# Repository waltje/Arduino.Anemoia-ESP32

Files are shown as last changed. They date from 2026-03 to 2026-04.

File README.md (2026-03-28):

<h1 align="center">
  <br>
  Anemoia
  <br>
  <b>Anemoia-ESP32</b>
  <br>
</h1>

<p align="center">
  Anemoia-ESP32 is a rewrite and port of the Anemoia Nintendo Entertainment System (NES) emulator running directly on the ESP32.  
  It is written in C++ and is designed to bring classic NES games to the ESP32.  
  This project focuses on performance, being able to run the emulator at native speeds and with full audio emulation implemented. However, games with complex mappers may induce a small speed loss.
  <br/>
  Anemoia-ESP32 is available on GitHub under the <a href="https://github.com/Shim06/Anemoia-ESP32/blob/main/LICENSE" target="_blank">GNU General Public License v3.0 (GPLv3)</a>.
</p>

<div align="center">
  <video src="https://github.com/user-attachments/assets/2b766040-4717-4ae2-9f72-5637c5ec5cd3"> </video>
</div>

---

## Sponsor

[NextPCB](https://www.nextpcb.com?code=Shim)

This project is proudly sponsored by [NextPCB](https://www.nextpcb.com?code=Shim). Their support helps fund the development and continuation of this project, and I'm very grateful to have them as my first ever sponsor. 

Want to make a PCB? NextPCB offers PCB fabrication and assembly services with fast turnaround times and affordable pricing to help bring your electronics projects to the next level.

---

## Table of Contents

- [Performance](#performance)
- [Compatibility](#compatibility)
- [Hardware Overview](#hardware-overview)
  - [Where to Buy](#where-to-buy)
  - [Default Pin Setup](#default-pin-setup)
- [Controls](#controls)
  - [Menu Access](#menu-access)
  - [Controller Button Mappings](#controller-button-mappings)
- [Getting Started](#getting-started)
  - [Option 1 - Web Flash](#option-1---web-flash-recommended)
  - [Option 2 - Build from Source](#option-2---build-from-source)
  - [After Flashing](#after-flashing)
- [How to Build and Upload](#how-to-build-and-upload)
- [Contributing](#contributing)
- [License](#license)

---

## Performance
Anemoia-ESP32 is heavily optimized to achieve native NES speeds on the ESP32, running at ~60.098 FPS (NTSC) with 1 frame skip and full audio emulation enabled.

Here are the performance benchmarks for several popular NES games. 
> [!NOTE]
> The following benchmarks show average framerates recorded over 8192 frames (~2 minutes) of emulation time. Some games, such as `Kirby's Adventure`, which frequently switch banks may experience significant FPS drops in certain sections.

| Game | Mapper | Average FPS |
|---|---|---|
| **Super Mario Bros.** | NROM (0)  | **60.10 FPS** |
| **Contra** | UxROM (2) | **60.10 FPS** |
| **The Legend of Zelda** | MMC1 (1)  | **60.10 FPS** |
| **Mega Man 2** | MMC1 (1)  | **60.10 FPS** |
| **Castlevania** | UxROM (2) | **60.10 FPS** |
| **Metroid** | MMC1 (1)  | **60.10 FPS** |
| **Kirby’s Adventure** | MMC3 (4)  | **59.57 FPS** |
| **Donkey Kong** | NROM (0)  | **60.10 FPS** |

## Compatibility

As of now, Anemoia-ESP32 has implemented six major memory mappers:
* Mapper 0
* Mapper 1
* Mapper 2
* Mapper 3
* Mapper 4
* Mapper 69

Totalling to around 79% of the entire NES game catalogue. 

If you'd like to check if a certain game is supported, visit 
[NesCartDB](https://nescartdb.com/) and search for the game on the 
right-hand side of the site. Select the specific game version
and look for the `iNES Mapper` number in the cart properties.
The game should be supported if the iNES Mapper number is in the list
of implemented mappers above.

Feel free to open an issue if a game has glitches or fails to boot.

---

## Hardware Overview
Anemoia-ESP32 requires a dual-core ESP32 with a minimum of 1 MB flash memory and <u><strong>NO PSRAM IS REQUIRED</strong></u>.

- ESP32
  - e.g. ESP32-DevKitC or ESP32-WROOM-32
- A 320x240 SPI TFT screen (no touch needed)
  - Either an ST7789-based screen as depicted, or
  - an ILI9341-based screen with 320x240 pixels
- Audio Amplifier
  - e.g. a PAM8403 or PAM8302
- Speaker
- MicroSD card module
- 8 Tactile push buttons, or
- Supported Controller
  - NES controller
  - SNES controller
  - PS1 controller
  - PS2 controller

> [!NOTE]
> ST7789-based displays are recommended as they seem to fare better with 80MHz SPI speeds and are the most compatible. ILI9341-based screens may experience screen problems at higher SPI speeds.

## Where to Buy
These are the recommended parts to use for this project.<br>
*These are affiliate links. Buying through them helps support me at no extra cost to you. Thank you for your support.*

- [ESP32](https://s.click.aliexpress.com/e/_c3B4YJhz)
- [240x320 ST7789 Display](https://s.click.aliexpress.com/e/_c2wkMWbV)
- [PAM8403 Amplifier Module](https://s.click.aliexpress.com/e/_c3EWffgT)
- [MicroSD Card Module](https://s.click.aliexpress.com/e/_c3ORlv7p)
- [TP4056 Charging Module](https://s.click.aliexpress.com/e/_c2xSu8Mn)
- [S09 Buck Converter](https://s.click.aliexpress.com/e/_c4LFB5JD)
- [SS12F17 Slide Switch](https://s.click.aliexpress.com/e/_c3DdrYLV)
- [12×12×7.3mm Tactile Push Buttons](https://s.click.aliexpress.com/e/_c3ABhrhV)
- [40mm Speaker](https://s.click.aliexpress.com/e/_c4Ci9359)

## Default Pin Setup
Default pin schematic

### TFT Display
| Signal | ESP32 Pins |
|---|---|
| MOSI | GPIO23 |
| MISO | -1 (N/A) |
| SCLK | GPIO18 |
| CS | GPIO4 |
| DC | GPIO2 |
| RST | EN |

### MicroSD
| Signal | ESP32 Pins |
|---|---|
| MOSI | GPIO13 |
| MISO | GPIO12 |
| SCLK | GPIO14 |
| CS | GND |

> [!IMPORTANT]
> 3V3-microsd-module-img
>
> If using this **3.3V microSD card module**, the pull-up resistor on **MISO (GPIO12)** must be **removed**. GPIO12 is a bootstrapping pin (MTDI) that must be LOW during boot. The external pull-up on the microSD module conflicts with the boot strapping process, preventing the ESP32 from booting correctly.

### Audio Amplifier
| Signal | ESP32 Pins |
|---|---|
| Input | GPIO25 |
              
### Controller
There are currently three input methods: Tactile push buttons, an NES/SNES controller, and a PS1/PS2 controller.

### Tactile Push Buttons
| Signal | ESP32 Pins |
|---|---|
| A | GPIO19 & GND |
| B | GPIO26 & GND |
| Left | GPIO32 & GND |
| Right | GPIO33 & GND |
| Up | GPIO15 & GND |
| Down | GPIO5 & GND |
| Start | GPIO27 & GND |
| Select | GPIO16 (RX2) & GND |
<br>

### NES/SNES controller

NES/SNES controller Pinout

| Signal | ESP32 Pins |
|---|---|
| Clock | GPIO22 |
| Latch | GPIO27 |
| Data | GPIO35 |
<br>

### PS1/PS2 controller

PS1/PS2 controller Pinout

| Signal | ESP32 Pins |
|---|---|
| Data | GPIO17 (TX2) |
| Command | GPIO22 |
| Attention | GPIO19 |
| Clock | GPIO23 |
<br>

Also connect the power and ground lines if using a controller. 
Most controllers should work fine from 3.3V power supply. 

---

## Controls

### Menu Access
Press **Start + Select** simultaneously in a game to open the menu.

### Controller Button Mappings

#### SNES Controller
| NES Button | SNES Buttons |
|---|---|
| A | B, A, R |
| B | Y, X, L |
| Start | Start |
| Select | Select |
| Up | D-Pad Up |
| Down | D-Pad Down |
| Left | D-Pad Left |
| Right | D-Pad Right  |

#### PS1/PS2 Controller
| NES Button | PS1/PS2 Buttons |
|---|---|
| A | R1, R2, R3, X, O |
| B | L1, L2, L3, Square, Triangle |
| Start | Start |
| Select | Select |
| Up | D-Pad Up |
| Down | D-Pad Down |
| Left | D-Pad Left |
| Right | D-Pad Right |

---

## Getting Started

### Option 1 - Web Flash (Recommended)
No software installation required.

1. Visit the [Web Flash](https://shim06.github.io/Anemoia-ESP32/) website.
2. Connect your ESP32 via USB.
3. Click **Flash** and select your ESP32's COM port.

> [!NOTE]
> Web flashing requires a Chromium-based browser (Chrome, Edge, Opera) with WebSerial support. Firefox is not supported.

### Option 2 - Build from Source

1. Build and upload the `Anemoia-ESP32.ino` program into the ESP32 following the [How to build and upload](#how-to-build-and-upload) instructions below.

---
### After Flashing
1. Format your microSD card to `FAT32`.
2. Put .nes game roms inside the root of the microSD card.
3. Insert the microSD card into the microSD card module.
4. Power on the ESP32 and select a game from the file select menu.

## How to build and upload

### Step 1

Either use `git clone https://github.com/Shim06/Anemoia-ESP32.git` on the command line to clone the repository or use Code → Download zip button and extract to get the files.

### Step 2
1. Download and install the Arduino IDE. 
2. In <b> File → Preferences → Additional boards manager URLs </b> , add:
```cmd
https://espressif.github.io/arduino-esp32/package_esp32_index.json
```
3. Download the ESP32 board support `v3.2.1` through <b> Tools → Board → Boards Manager </b>. 
> [!IMPORTANT]
> Make sure to download version 3.2.1, as different board versions may have worse performance.
4. Download the `SdFat` and `TFT_eSPI` libraries from <b> Tools → Manage Libraries </b>.

### Step 3 - Configure TFT_eSPI
Copy and paste the TFT_eSPI configuration file into the TFT_eSPI folder.
1. Navigate to your Arduino Libraries folder:
(Default location): `Documents/Arduino/libraries/TFT_eSPI`
2. Copy the provided `User_Setup.h` file from this repository into
`TFT_eSPI/` and overwrite the file. Optionally, edit the `#define` pins as desired.
> [!NOTE]
> If using a screen with the ILI9341 driver, open `User_Setup.h` in a text editor and comment out `#define ST7789_DRIVER` and uncomment `#define ILI9341_DRIVER`.
> ```C++
> // #define ST7789_DRIVER
> #define ILI9341_DRIVER
> ```

### Step 4 - Apply custom build flags
1. Locate your ESP32 Arduino platform directory. This is typically at:
```cmd
\Users\{username}\AppData\Local\Arduino15\packages\esp32\hardware\esp32\{version}\
```
2. Copy the `platform.txt` file from this repository and paste into that folder.
This file defines additional compiler flags and optimizations used by Anemoia-ESP32.
> [!WARNING]
> Backup your `platform.txt` file if you have your own custom settings already. 

### Step 5 - Upload
1. Connect your ESP32 via USB.
2. In the Arduino IDE, go to <b> Tools → Board </b> and select your ESP32 board (e.g., ESP32 Dev Module).
3. Click Upload or press `Ctrl+U` to build and flash the emulator. Optionally, edit the `#define` pins as desired.

## Contributing

Pull requests are welcome. For major changes, please open an issue first
to discuss what you would like to change.

## License

This project is licensed under the GNU General Public License v3.0 (GPLv3) - see the [LICENSE](LICENSE) file for more details.

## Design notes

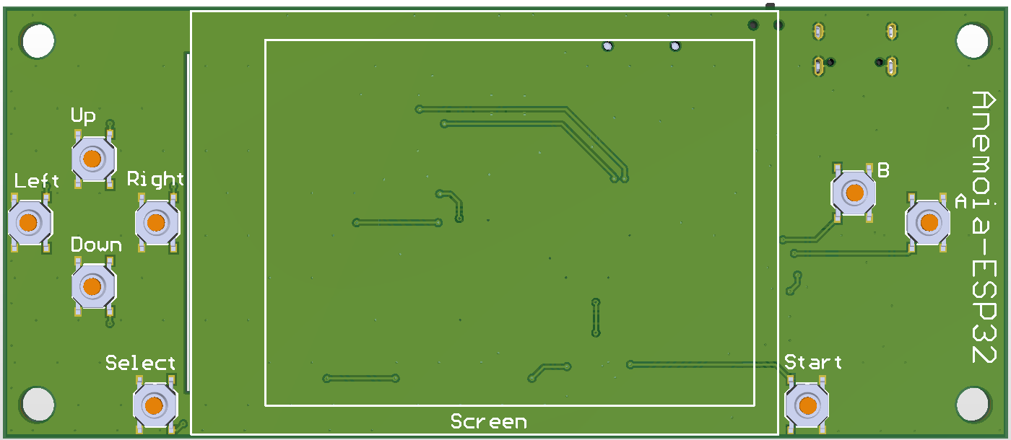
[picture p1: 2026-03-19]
hardware/Anemoia-ESP32-SMD/pcb/Anemoia-ESP32-SMD-Bottom.png

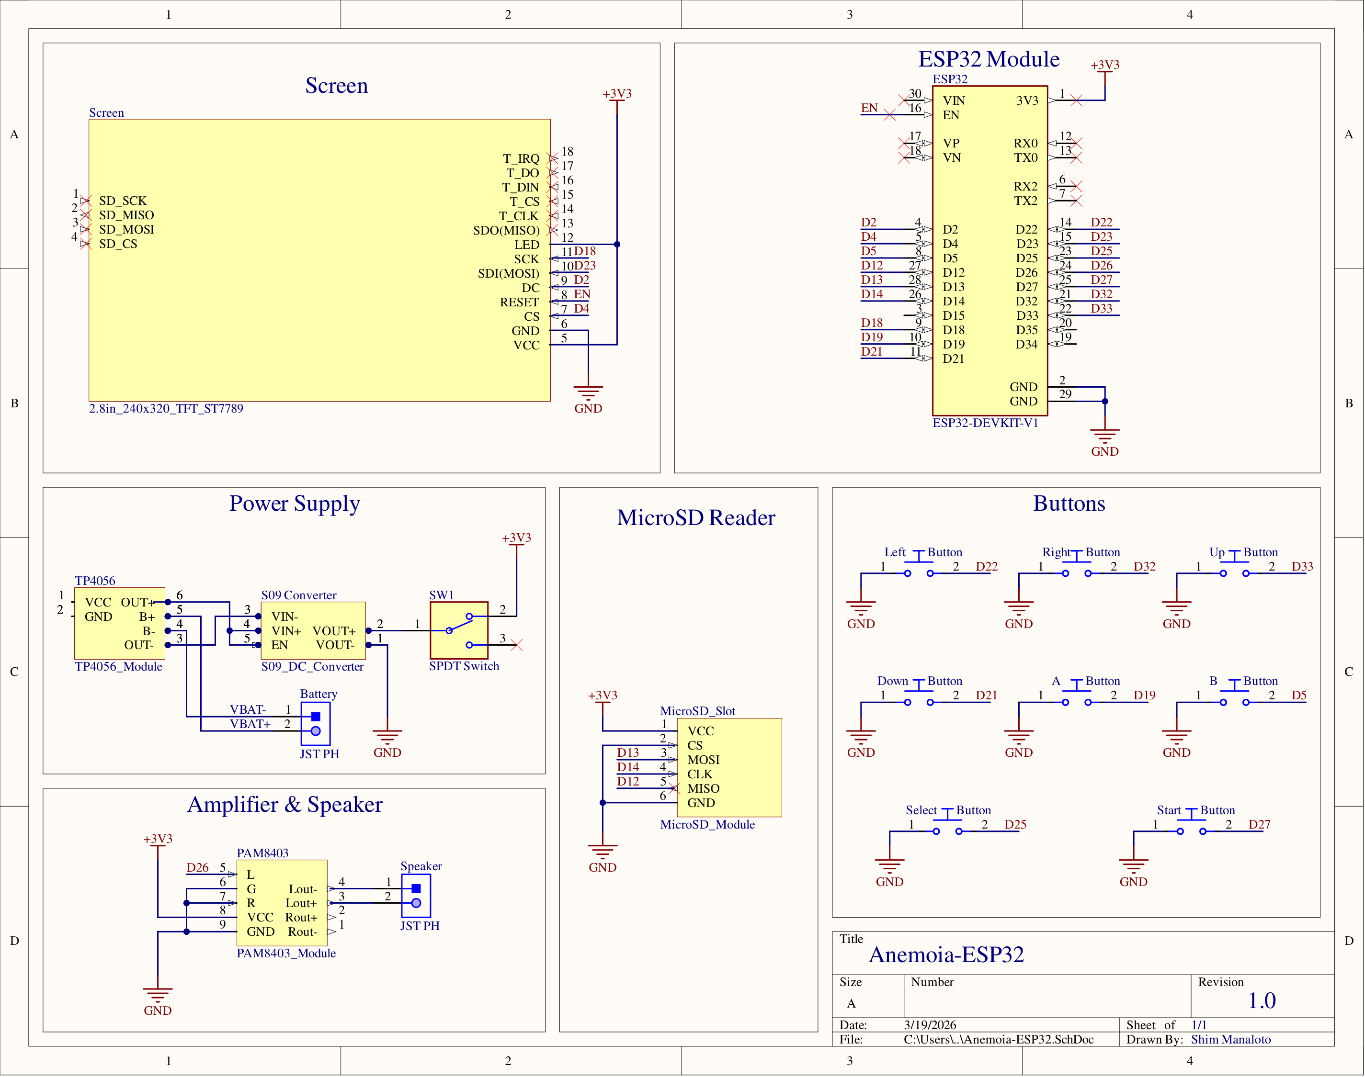
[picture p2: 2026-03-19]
hardware/Anemoia-ESP32/schematics/Anemoia-ESP32.png

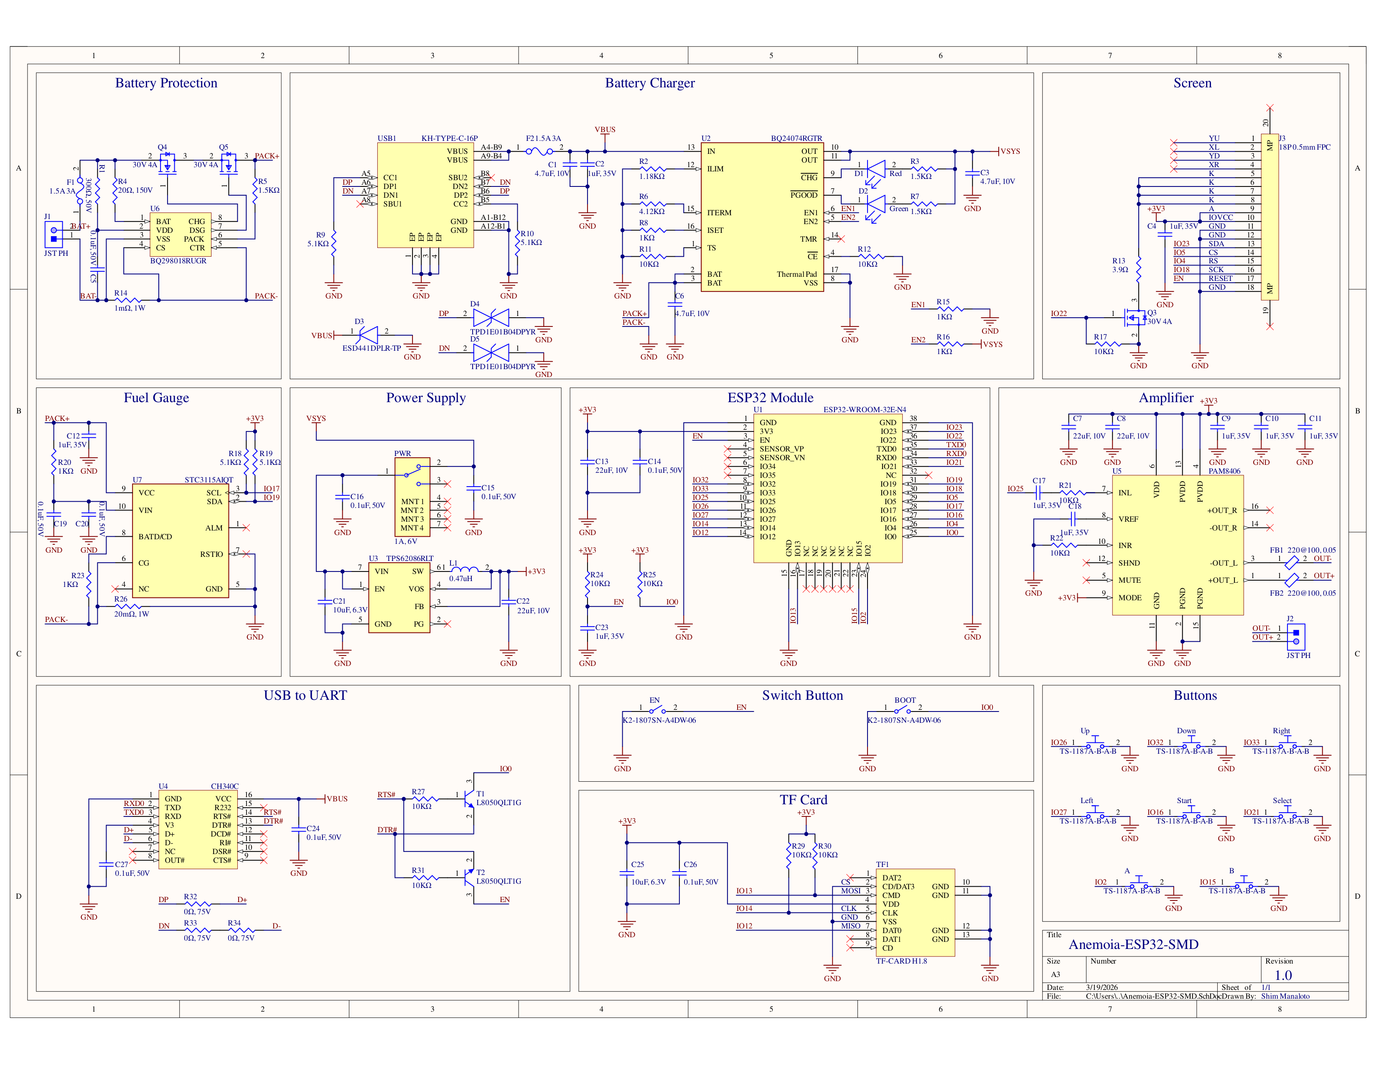
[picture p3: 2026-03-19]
hardware/Anemoia-ESP32-SMD/schematics/Anemoia-ESP32-SMD.png

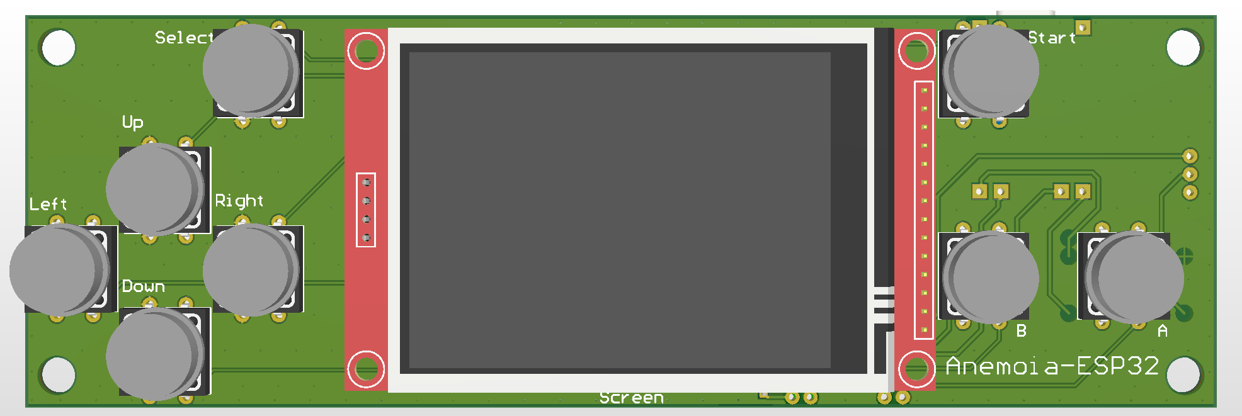
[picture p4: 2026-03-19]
hardware/Anemoia-ESP32/pcb/Anemoia-ESP32-Top.png

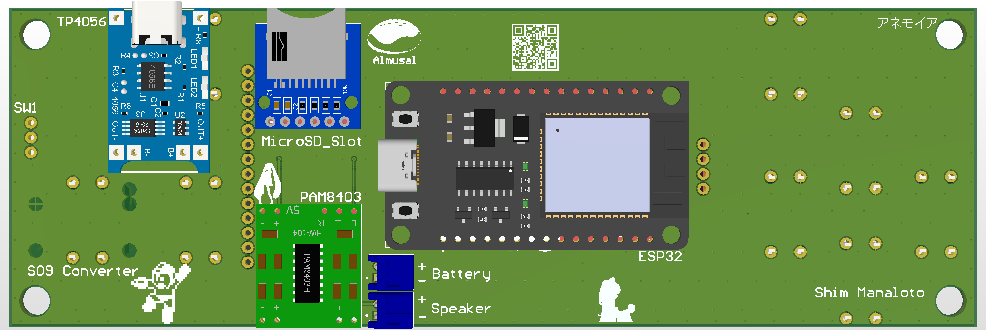
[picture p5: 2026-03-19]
hardware/Anemoia-ESP32/pcb/Anemoia-ESP32-Bottom.png

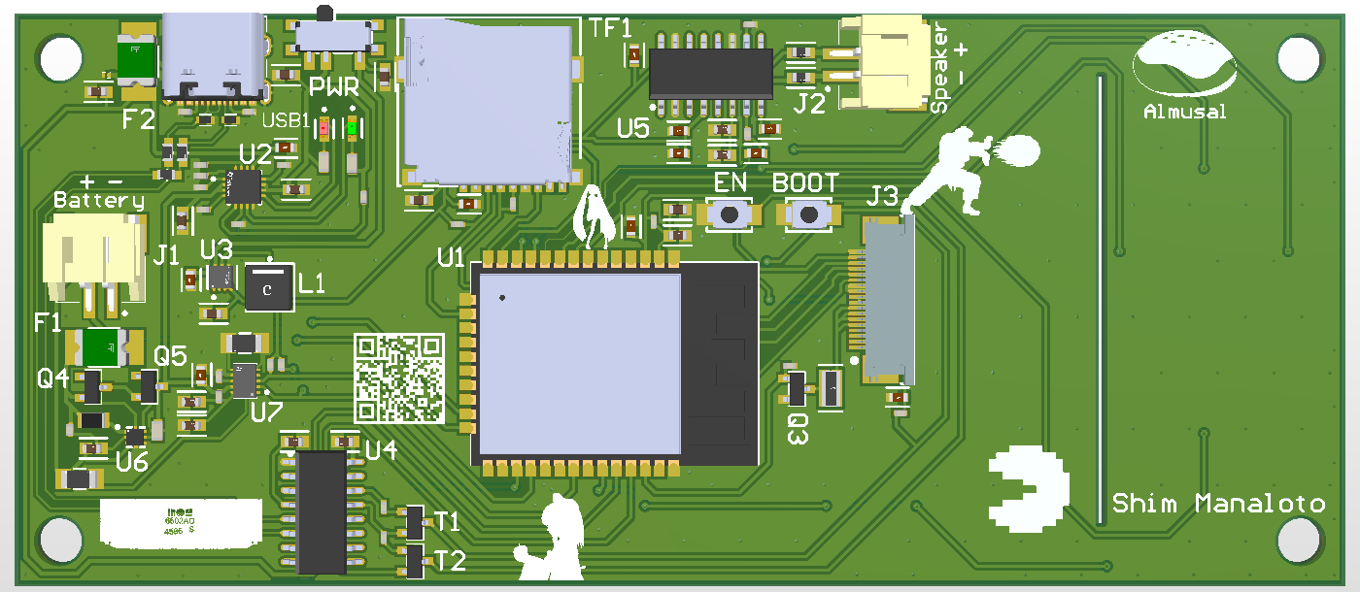
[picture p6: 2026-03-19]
hardware/Anemoia-ESP32-SMD/pcb/Anemoia-ESP32-SMD-Top.png

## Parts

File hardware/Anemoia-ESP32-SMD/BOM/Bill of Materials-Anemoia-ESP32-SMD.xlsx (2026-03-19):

Quantity | Manufacturer Part Number | Description | Designator | Case/Package | Footprint | Manufacturer
8 | TS-1187A-B-A-B | Without Bracket 5.1mm 12V 5.1mm Round Button No SPST 50mA SMD-4P,5.1x5.1mm Tactile Switches RoHS | A, B, Down, Left, Right, Select, Start, Up |  | SWITCH TACTILE SMD-4P,5.1x5.1mm
2 | K2-1807SN-A4DW-06 | 12V 2.9mm 4mm 50mA SMD,4x2.9mm Tactile Switches RoHS | BOOT, EN |  | SWITCH TACTILE MD,4x2.9mm
3 | CL10A475KP8NNNC | CAP CER 4.7uF 10V ±10% X5R 0603 | C1, C3, C6 | 0603 | CAP CER 0603 | Samsung Electro-Mechanics
9 | CL05A105KL5NRNC | CAP CER 1uF 35V ±10% X5R 0402 | C2, C4, C9, C10, C11, C12, C17, C18, C23 | 0402 | CAP CER SAMSUNG 0402 | Samsung Electro-Mechanics
9 | CC0603KRX7R9BB104 | CAP CER 0.1UF 50V X7R 0603 | C5, C14, C15, C16, C19, C20, C24, C26, C27 | 0603 | CAP CER 0603 | Yageo Group
4 | GRM188R61A226ME15D | CAP CER 22UF 10V X5R 0603 | C7, C8, C13, C22 | 0603 | CAP CER 0603 | Murata
2 | CL05A106MQ5NUNC | 6.3V 10uF X5R ±20% 0402 Ceramic Capacitors RoHS | C21, C25 | 0402 | CAP CER SAMSUNG 0402 | Samsung Electro-Mechanics
1 | XL-1608SURC-06 | LED RED WATER CLEAR 0603 SMD | D1 |  | Red LED 0603
1 | PSC-1608U52GC-G4 | LED GREEN WATER CLEAR 0603 SMD | D2 |  | Green LED 0603
1 | ESD441DPLR-TP | ESD DIODE 5.5VWM 20VC DFN0603-2 | D3 |  | DFN0603-2
2 | TPD1E01B04DPYR | 3.6VWM 9VC X1SON-2(0.6x1) | D4, D5 |  | X1-SON-2
2 | 1812L150/24MR | 24V 1.5A 20A 3A 40mΩ 1812 PTC Resettable Fuses RoHS | F1, F2 | 1812 | PTC 1812 | Littelfuse
2 | BLM18EG221SN1D | Chip Ferrite Bead, 0603, 220Ω @ 100MHz, 0.05Ω, 25%, 2A | FB1, FB2 | 0603 | 0603 FB | Murata
2 | S2B-PH-SM4-TB(LF)(SN) | 2P 1x2P PH Tin -25℃~+85℃ Beige 2mm 100V 2 2A 1 Surface Mount, Right Angle SMD,P=2mm,Surface Mount,Right Angle Headers, Male Pins RoHS | J1, J2 |  | JST_S2B-PH-SM4-TB(LF)(SN) | JST
1 | HC-FPC-0.5-18P-CXH20 | CONN FFC FPC 18POS 0.5mm BOTTOM CNT SMD R/A | J3 |  | FPC CN 18P 0.5mm
1 | XFL4015-471MEC | FIXED IND 470nH SMD,4x4mm | L1 |  | SMD,4x4mm
1 | MK-12C02-G020 | Surface Mount, Right Angle 1A SPDT 6V Black 10,000 Cycles SMD,6.6x1.4mm Slide Switches RoHS | PWR |  | MK-12C02-G020
3 | AO3402 | MOSFET N-CH 30V SOT-23 | Q3, Q4, Q5 |  | SOT-23
1 | RC0402FR-07300RL | RES 300Ω ±1% 62.5mW 0402 | R1 |  | RES 0402
1 | RC0402FR-071K18L | RES 1.18kΩ ±1% 62.5mW 0402 | R2 |  | RES 0402
3 | RC0603FR-071K5L | RES 1.5kΩ ±1% 100mW 0603 | R3, R5, R7 |  | RES 0603
1 | RC0805FR-0720RL | RES 20Ω ±1% 125mW 0805 | R4 |  | RES 0805
1 | RC0402FR-074K12L | RES 4.12kΩ ±1% 62.5mW 0402 | R6 |  | RES 0402
5 | RC0402FR-071KL | RES 1kΩ ±1% 62.5mW 0402 | R8, R15, R16, R20, R23 | 0402 | RES 0402 | Yageo Group
4 | RC0402FR-075K1L | RES 5.1kΩ ±1% 62.5mW 0402 | R9, R10, R18, R19 |  | RES 0402
11 | RC0402FR-0710KL | RES 10K OHM 1% 1/16W 0402 | R11, R12, R17, R21, R22, R24, R25, R27, R29, R30, R31 | 0402 | RES 0402 | Yageo Group
1 | LTR18EZPJ3R9 | RES 3.9Ω ±5% 750mW 0612 | R13 | 0612 | RES 0612 | ROHM
1 | FRM121WFR001TM | RES 1mΩ ±1% 1W 1206 | R14 |  | RES 1206
1 | FRM121WFR020TM | RES 20mΩ ±1% 1W 1206 | R26 |  | RES 1206
3 | RC0603FR-070RL | RES 0Ω ±1% 100mW 0603 | R32, R33, R34 | 0603 | RES 0OHM | Yageo Group
2 | L8050QLT1G | TRANS NPN 25V 800mA SOT-23 | T1, T2 |  | SOT-23
1 | TF-CARD H1.8 | Push-Push 1.8mm MicroSD Card (TF Card) SMD PC Card Sockets RoHS | TF1 |  | TF-CARD H1.8
1 | ESP32-WROOM-32E-N4 | WLAN+BT Module 2412MHz to 2484MHz 47-Pin SMD Module | U1 |  | ESP32-WROOM-32E-N4 | Espressif Systems
1 | BQ24074RGTR | IC BATT CHG LI-ION 1CELL 16QFN | U2 | VQFN | BQ24074RGTR | Texas Instruments
1 | TPS62086RLTR | 2.4MHz Buck 3A Fixed 3.3V 1 VSON-7(2x2) Voltage Regulators - DC DC Switching Regulators RoHS | U3 | VQFN | VSON-7(2x2) | Texas Instruments
1 | CH340C | USB to Serial Port chip | U4 |  | SOP-16
1 | PAM8406 | 5W Stereo Audio Amplifier | U5 |  | SOP-16
1 | BQ298018RUGR | High-side protector for single-cell li-ion and li-polymer batteries 8-X2QFN -40 to 85 | U6 |  | X2-QFN-8(1.5x1.5) | Texas Instruments
1 | STC3115AIQT | Battery Fuel Gauge, Li-Ion, Li-Pol, 2.7V to 4.2V Supply, I2C Interface, DFN-10 | U7 | DFN | DFN-10(2x3) | STMicroelectronics
1 | KH-TYPE-C-16P | CONN RCPT Type-C 16POS SMD R/A | USB1 |  | USB-C-SMD_KH-TYPE-C-16P

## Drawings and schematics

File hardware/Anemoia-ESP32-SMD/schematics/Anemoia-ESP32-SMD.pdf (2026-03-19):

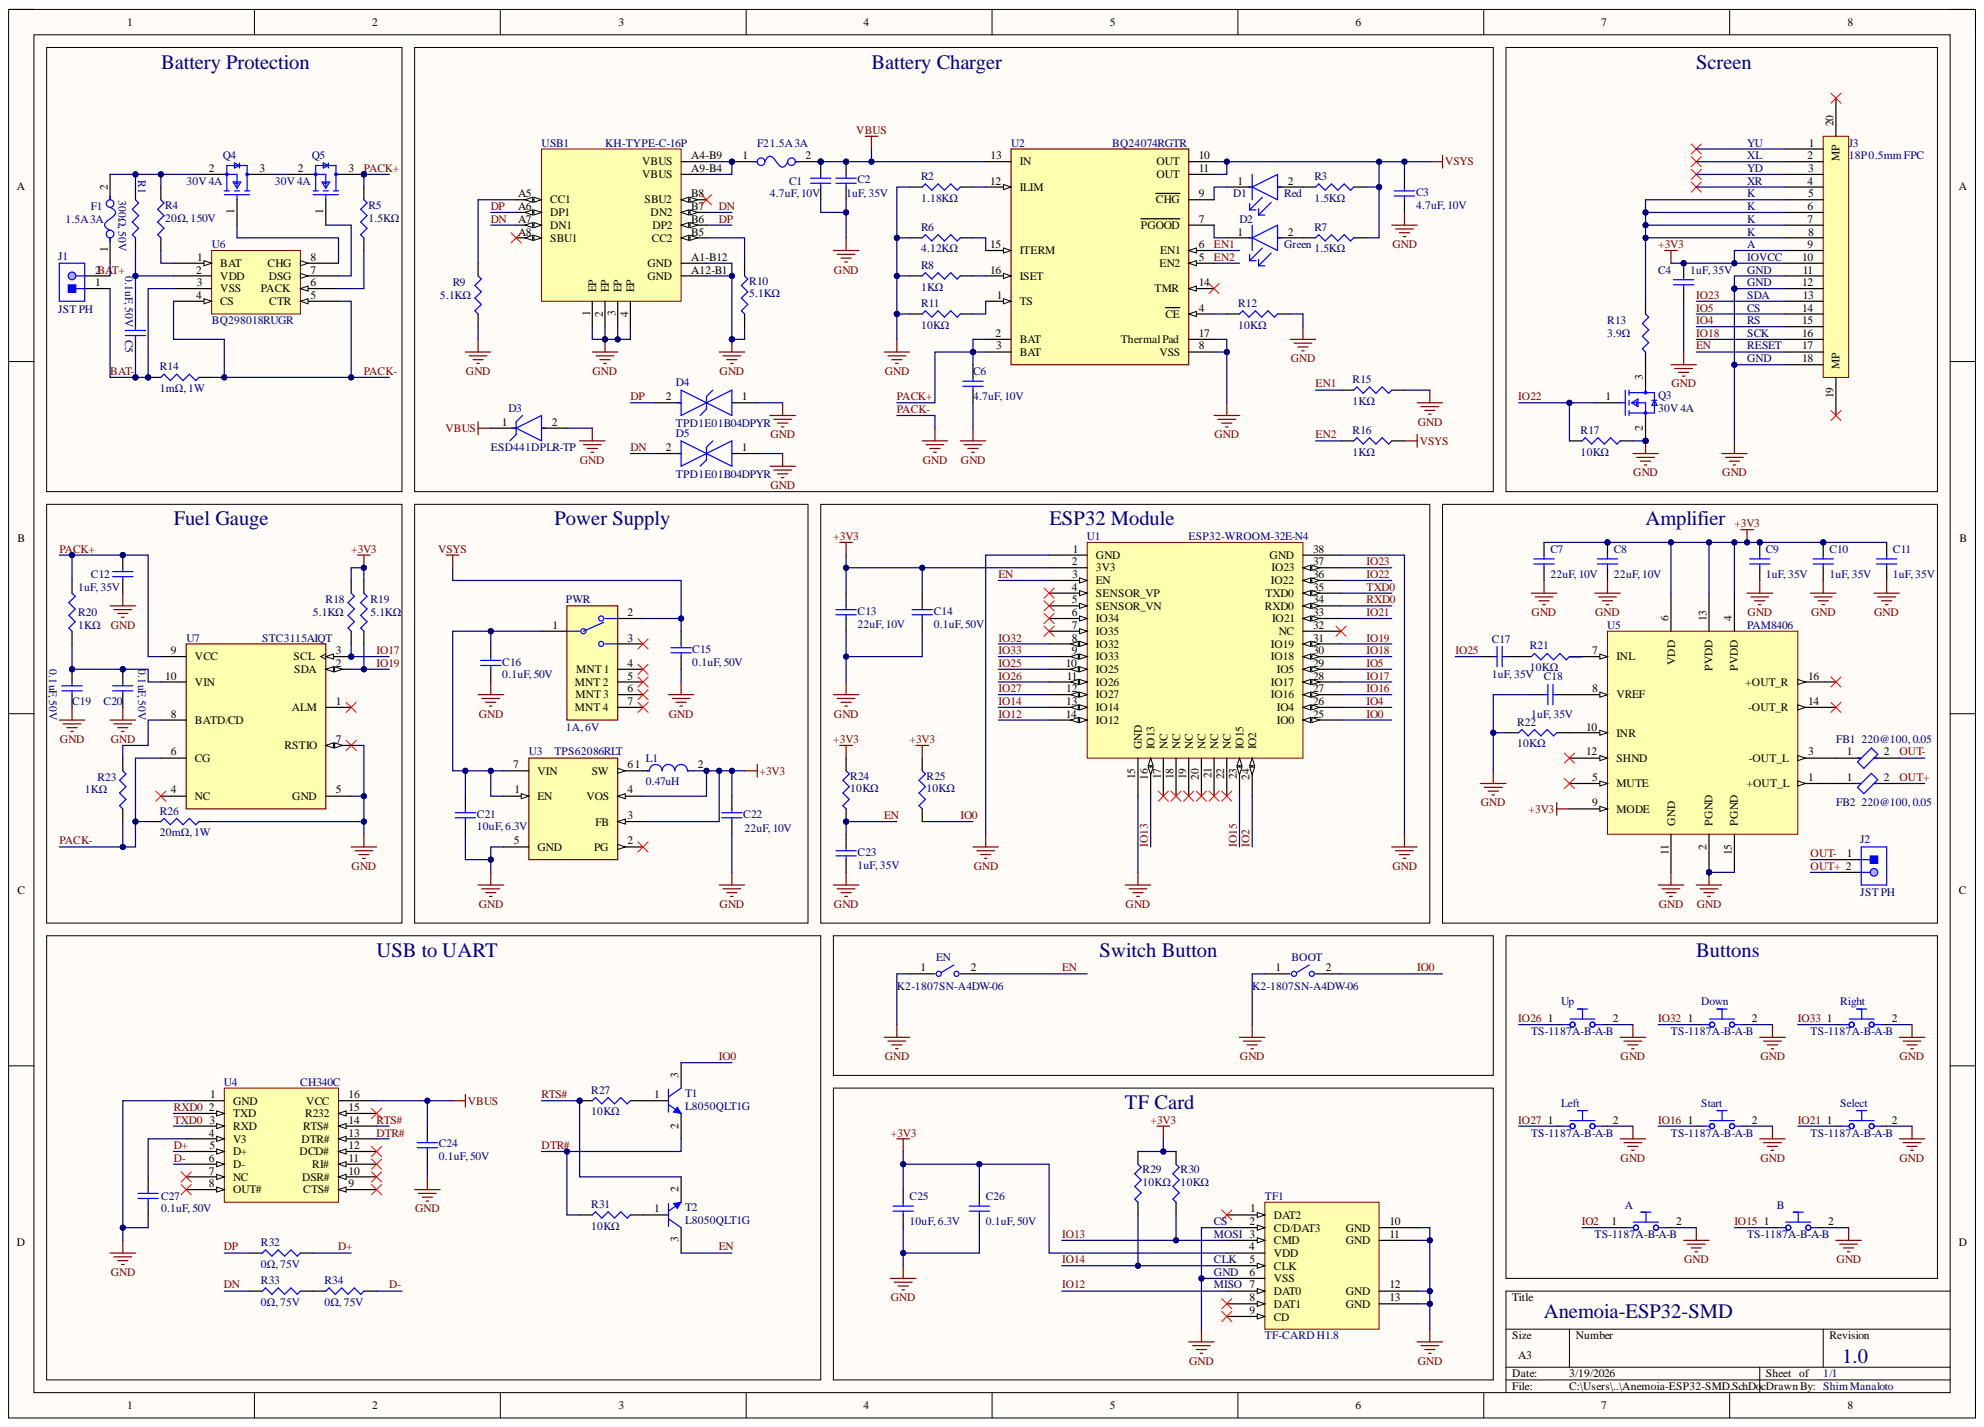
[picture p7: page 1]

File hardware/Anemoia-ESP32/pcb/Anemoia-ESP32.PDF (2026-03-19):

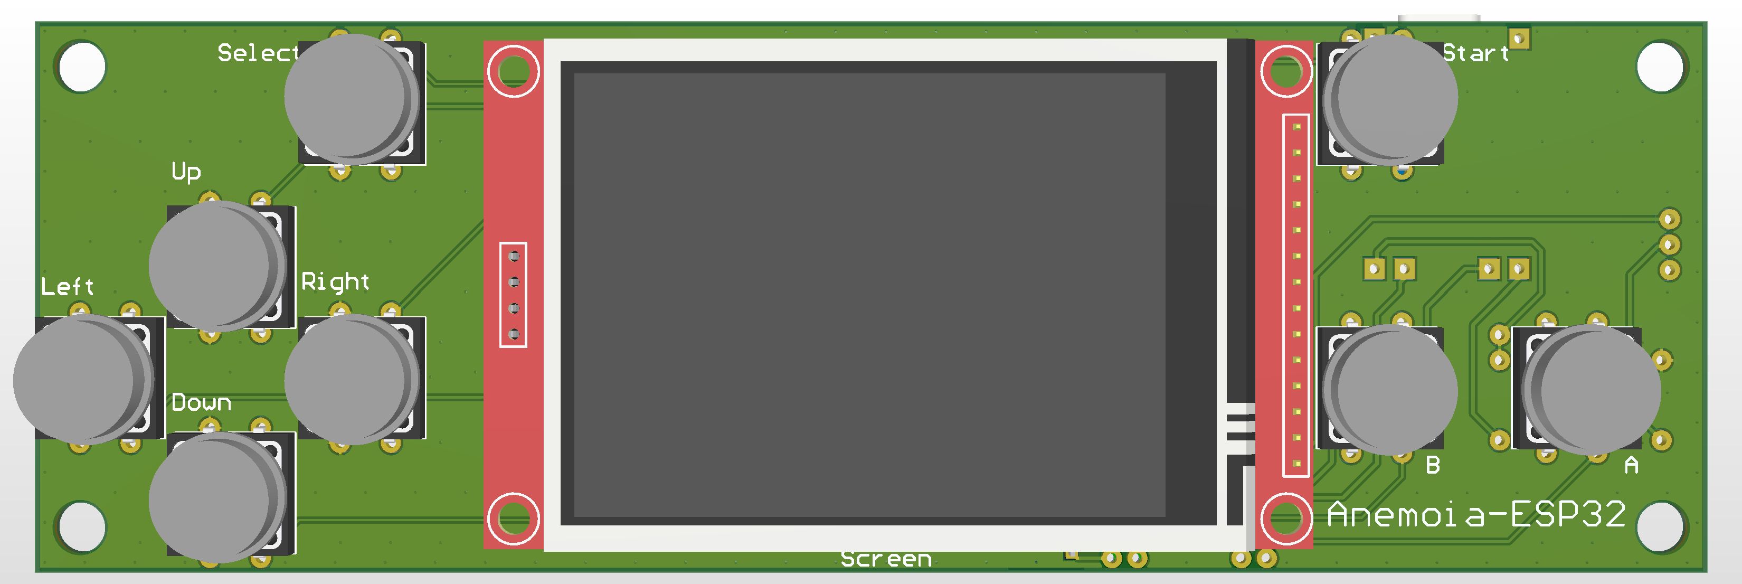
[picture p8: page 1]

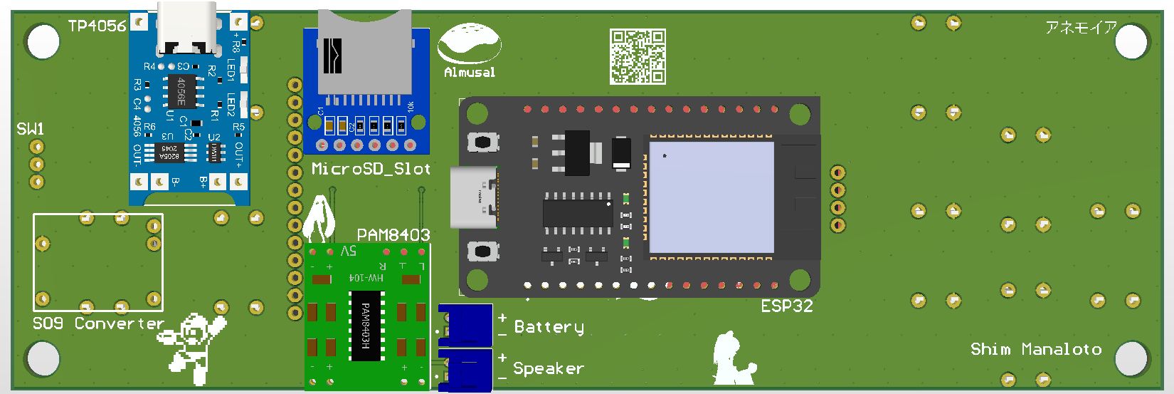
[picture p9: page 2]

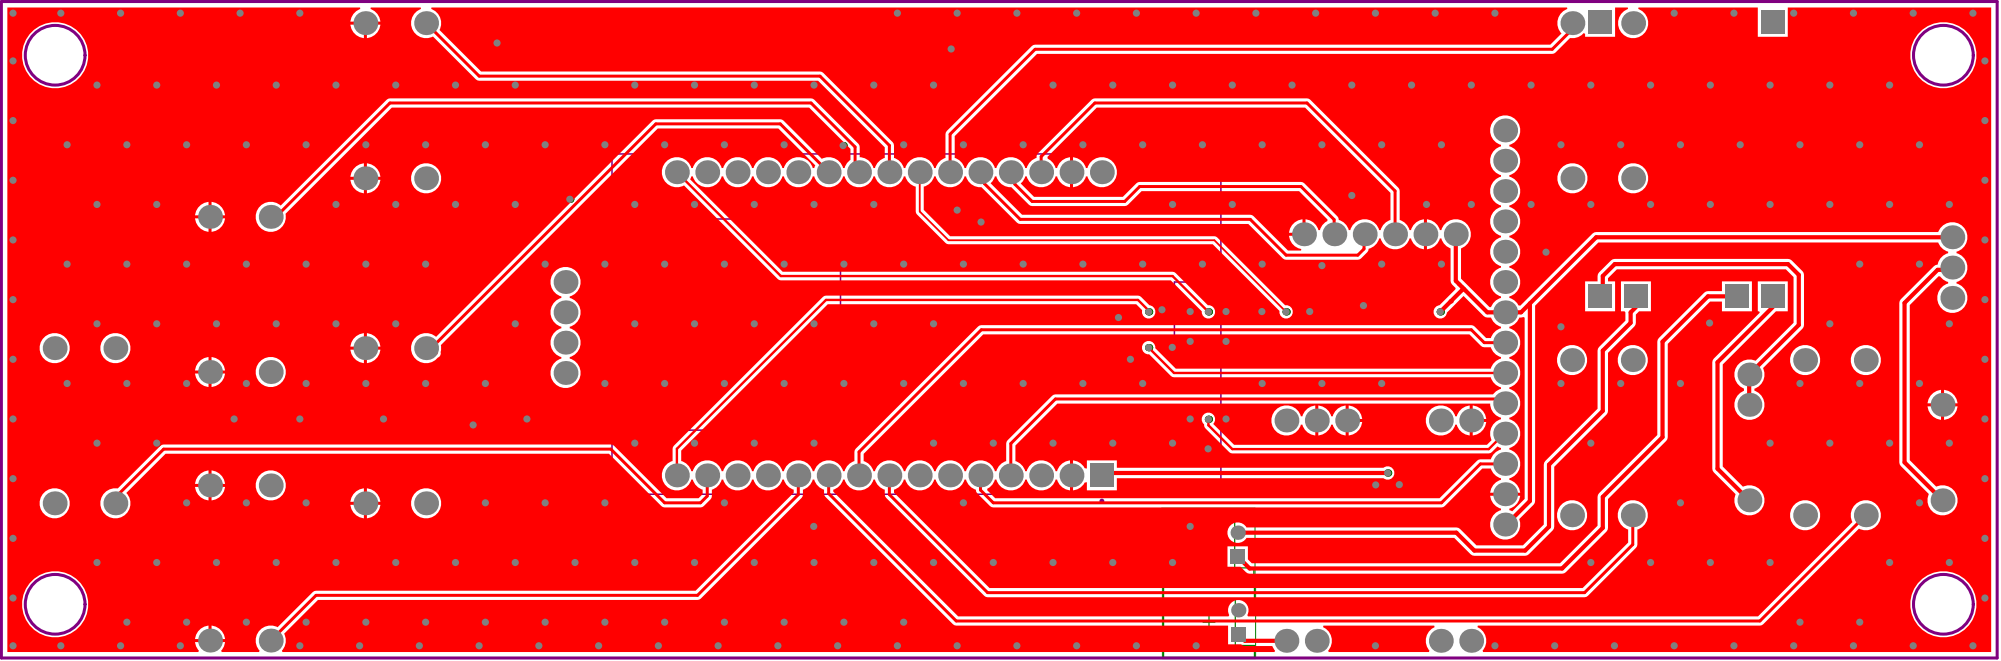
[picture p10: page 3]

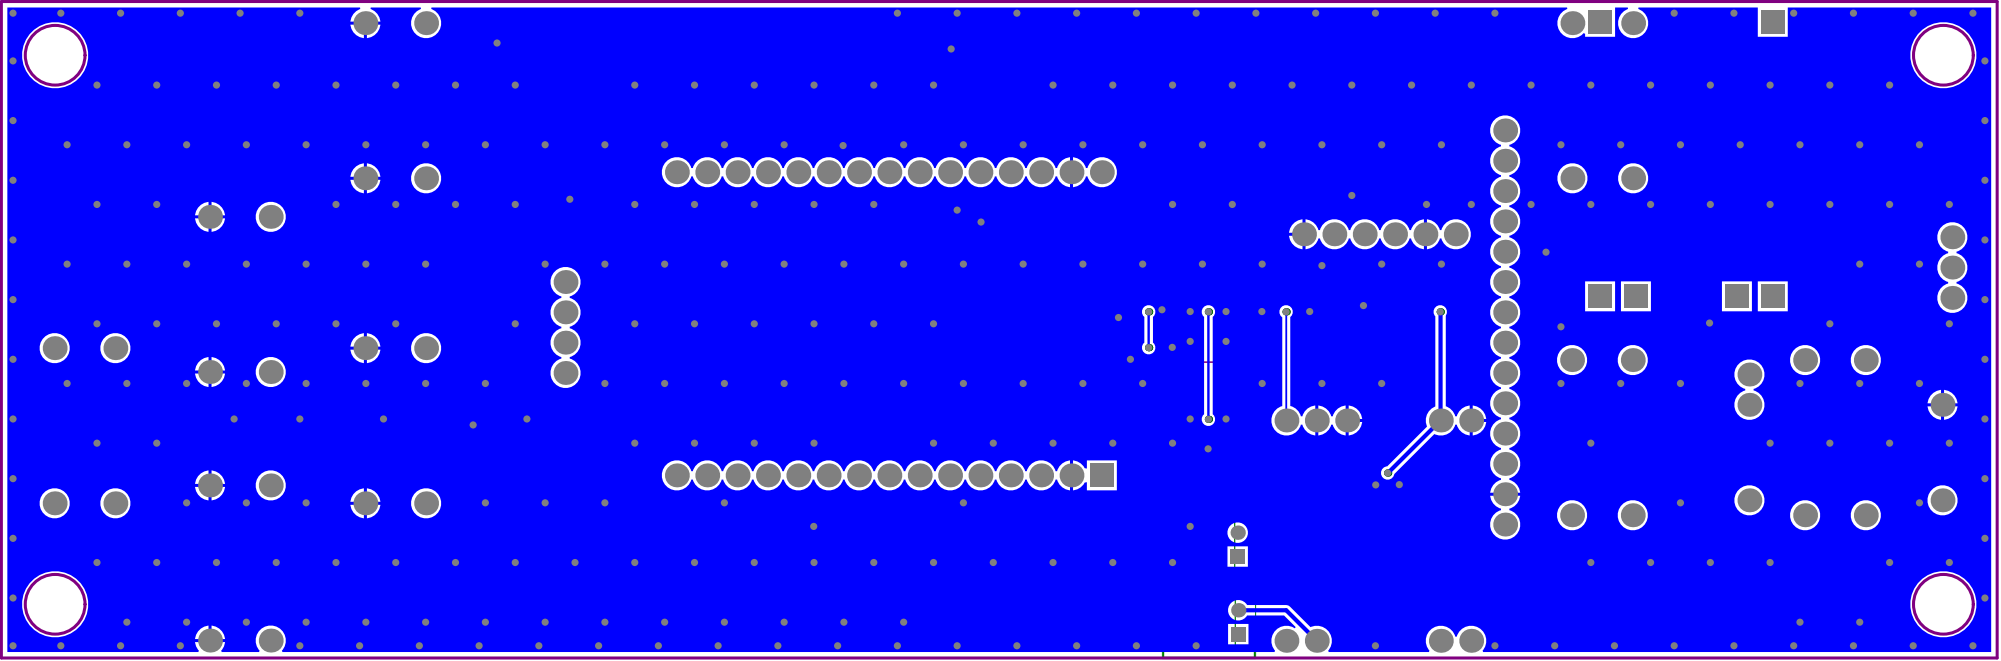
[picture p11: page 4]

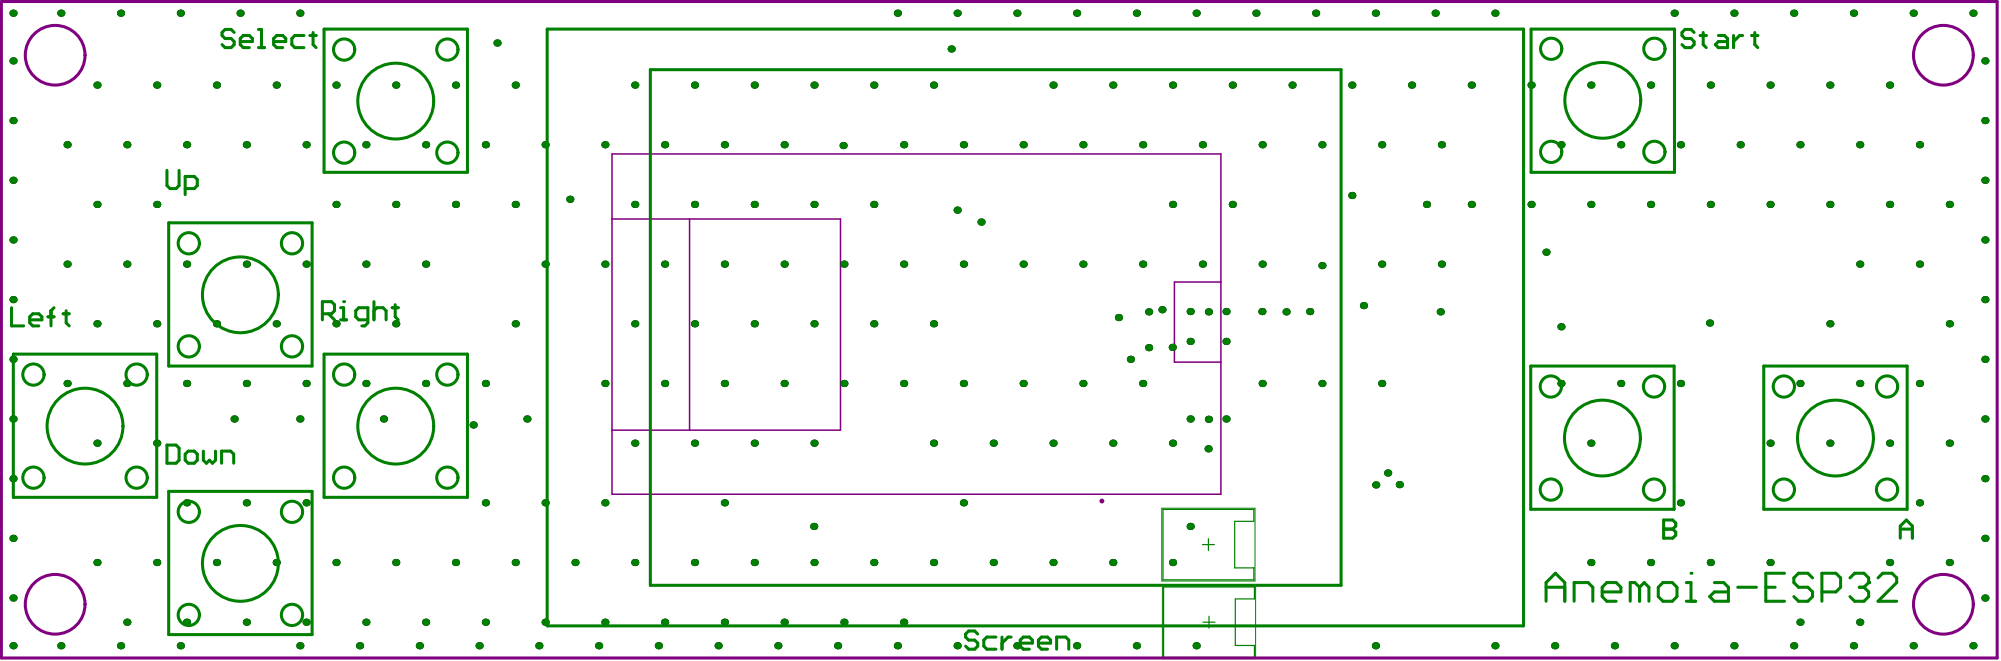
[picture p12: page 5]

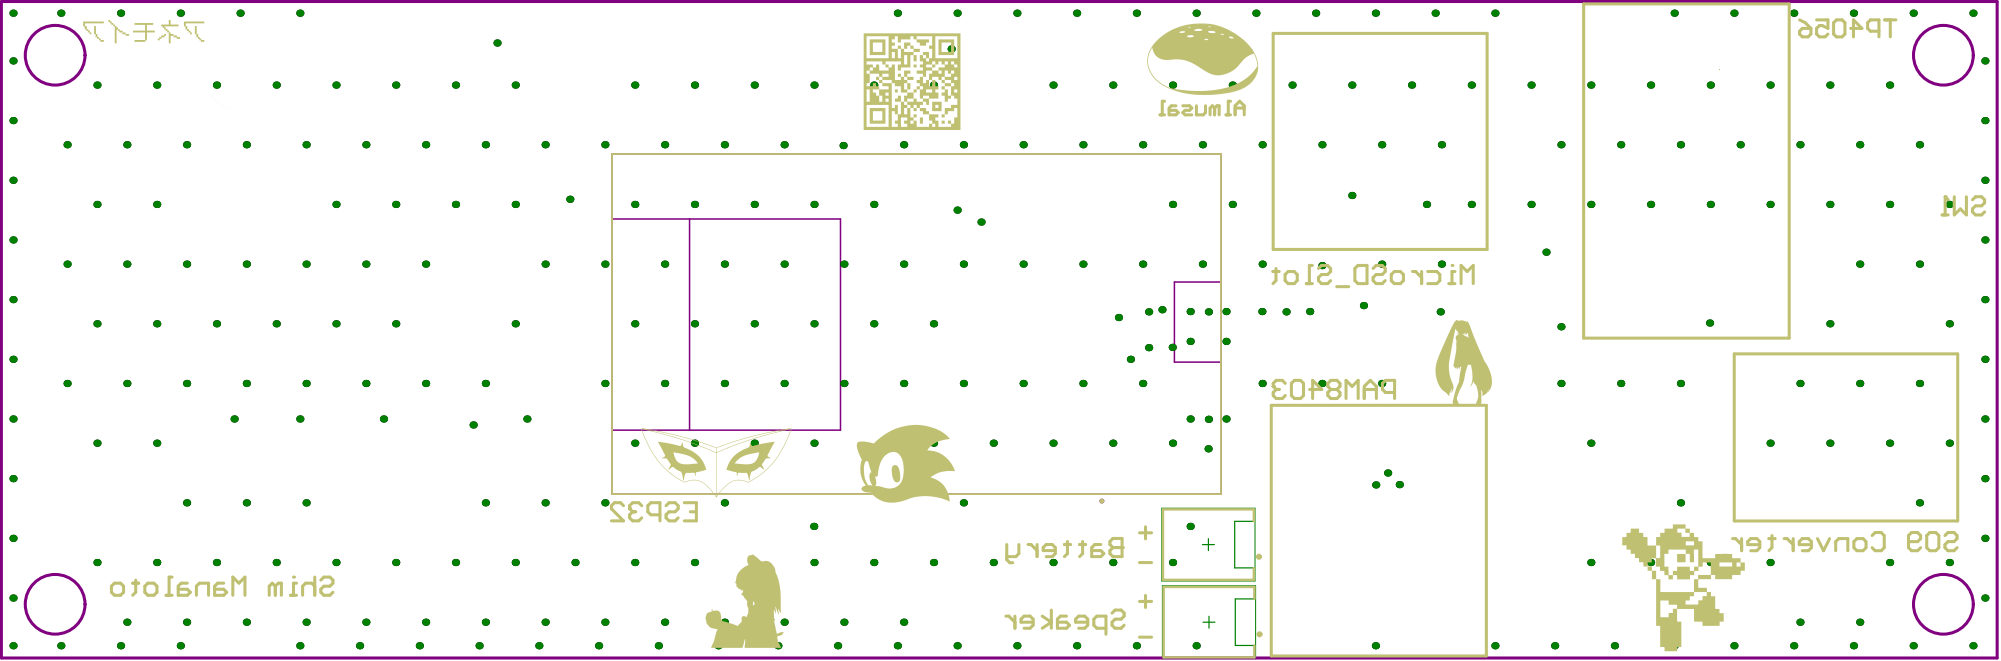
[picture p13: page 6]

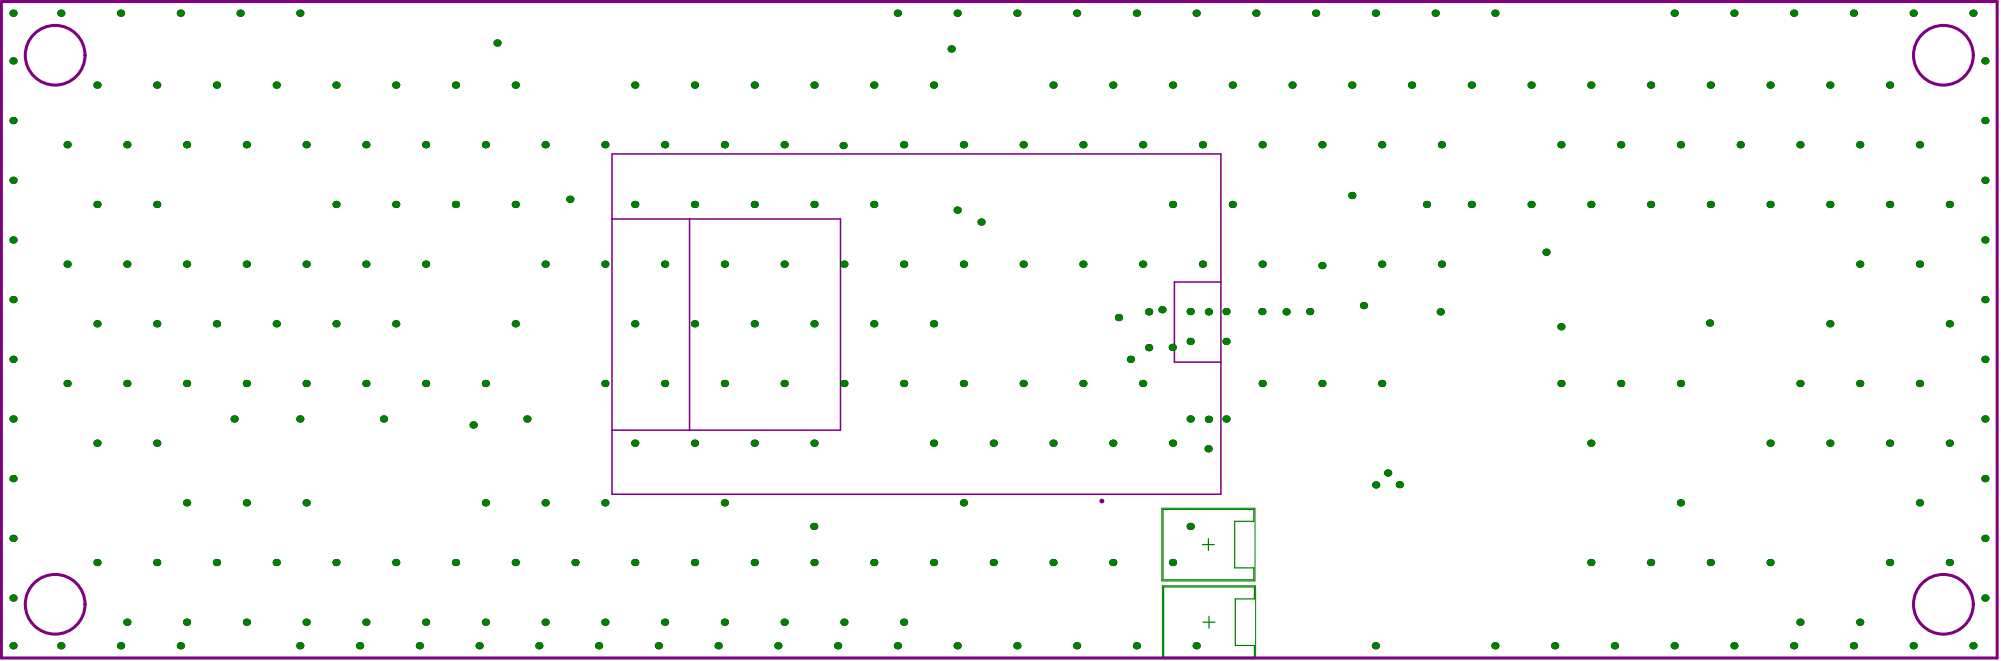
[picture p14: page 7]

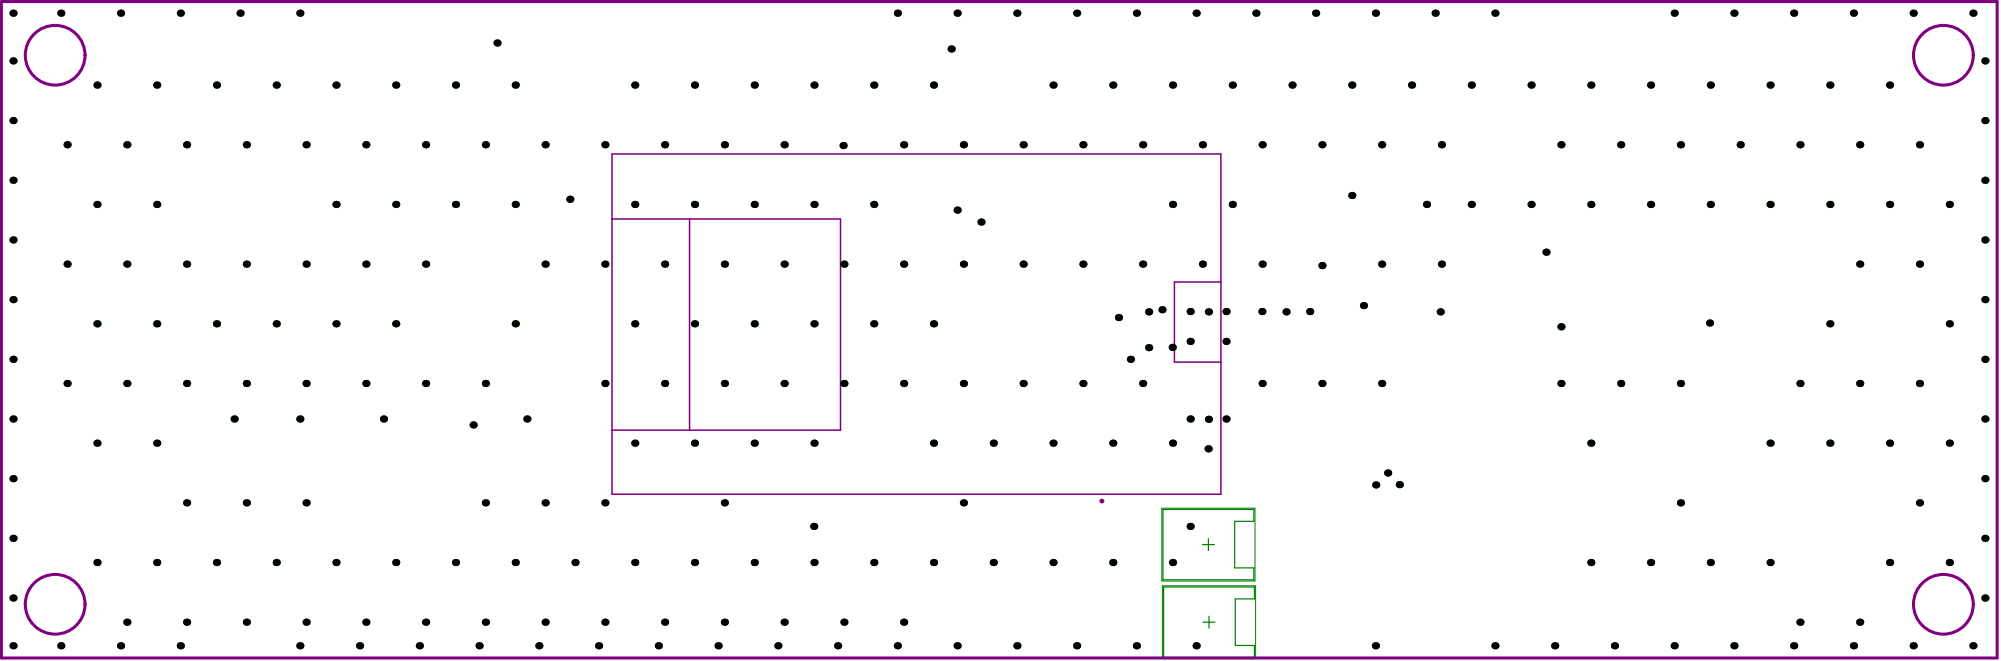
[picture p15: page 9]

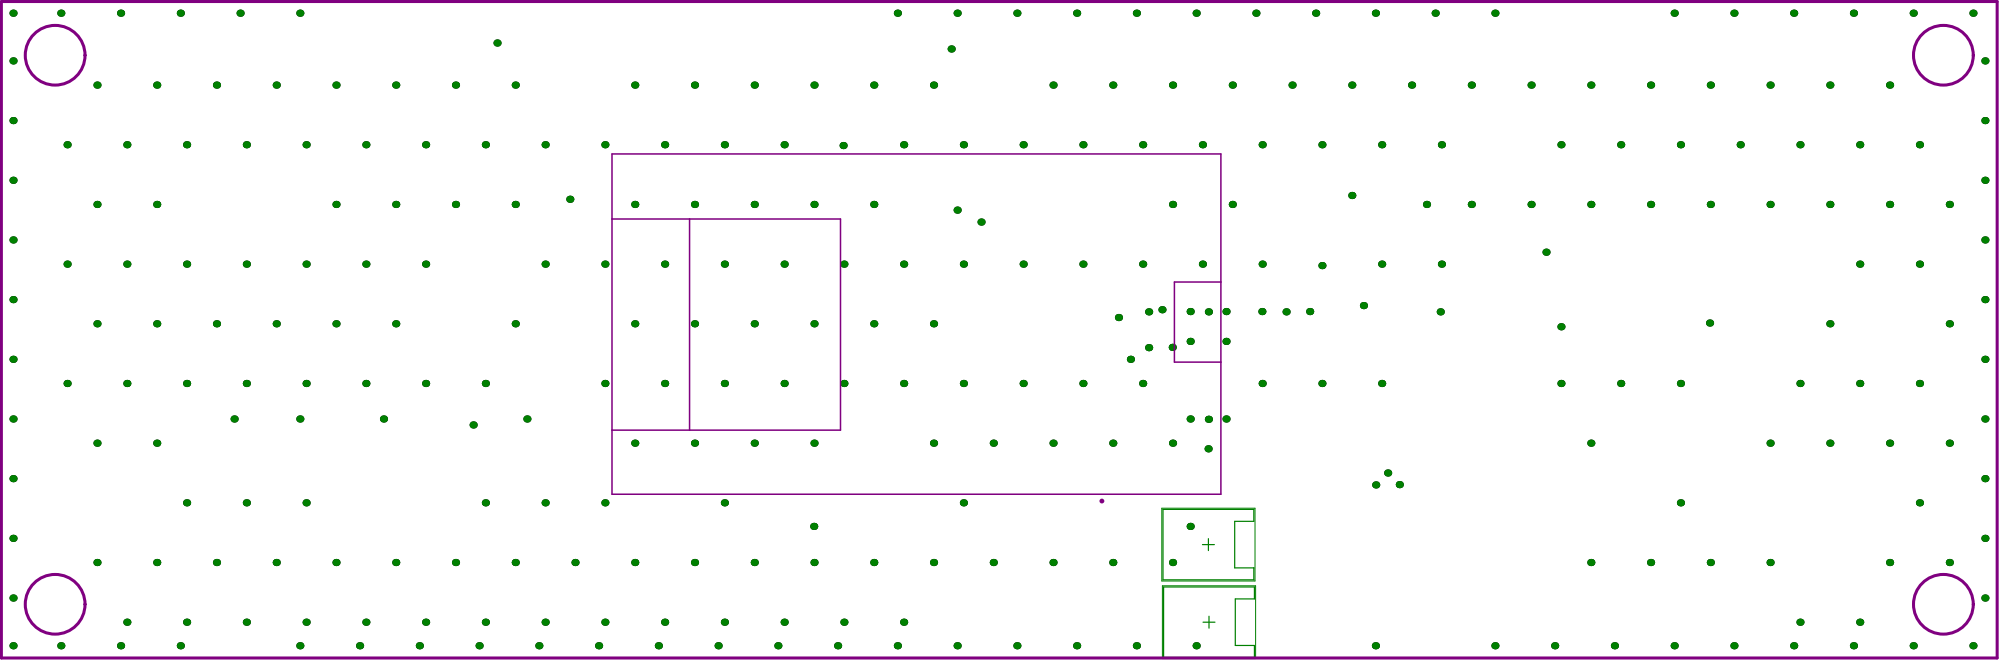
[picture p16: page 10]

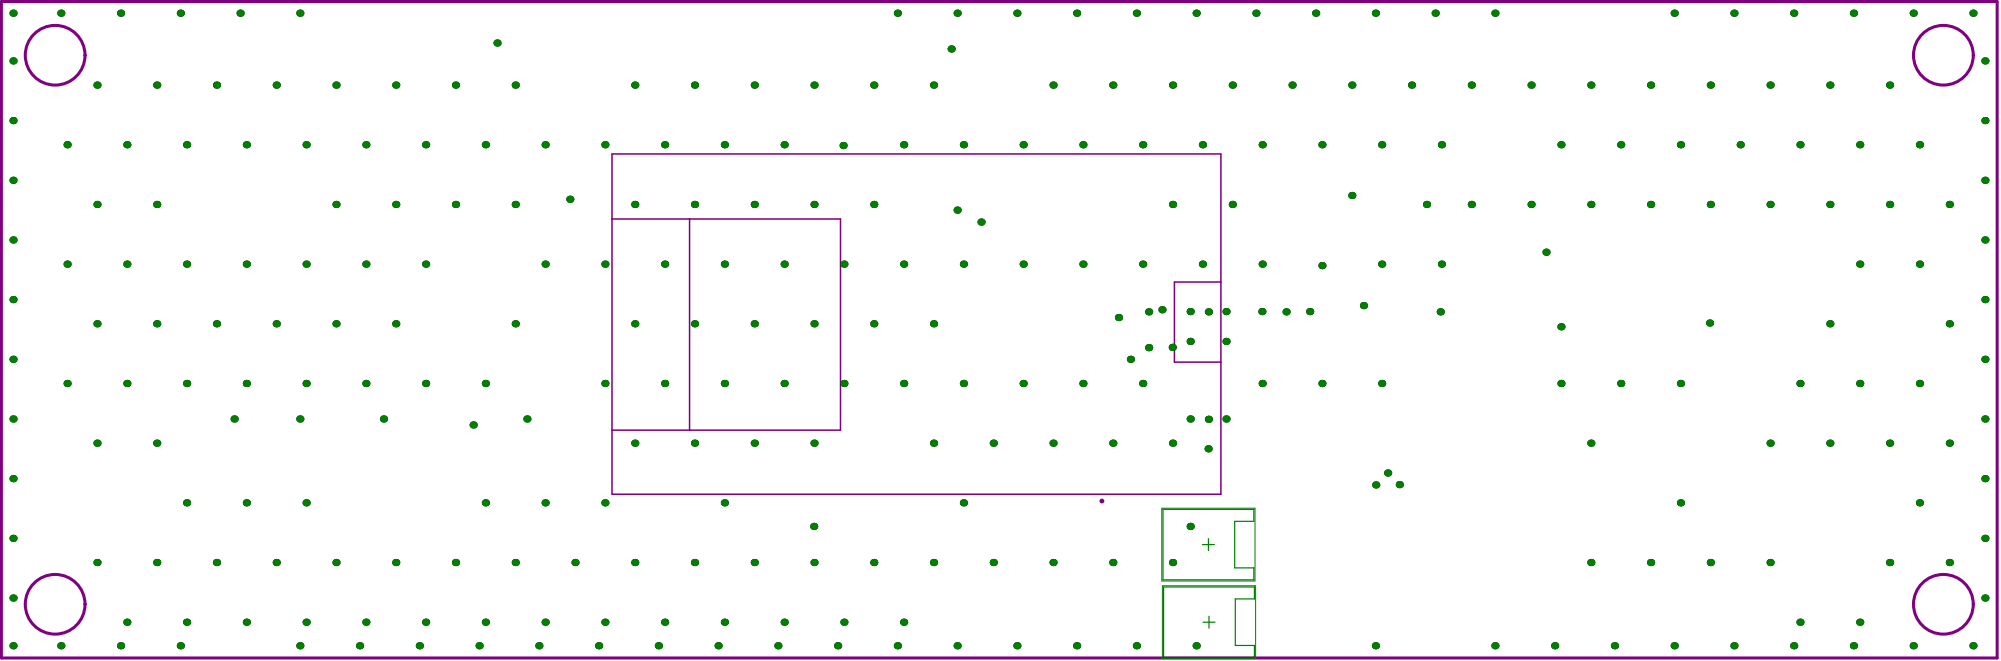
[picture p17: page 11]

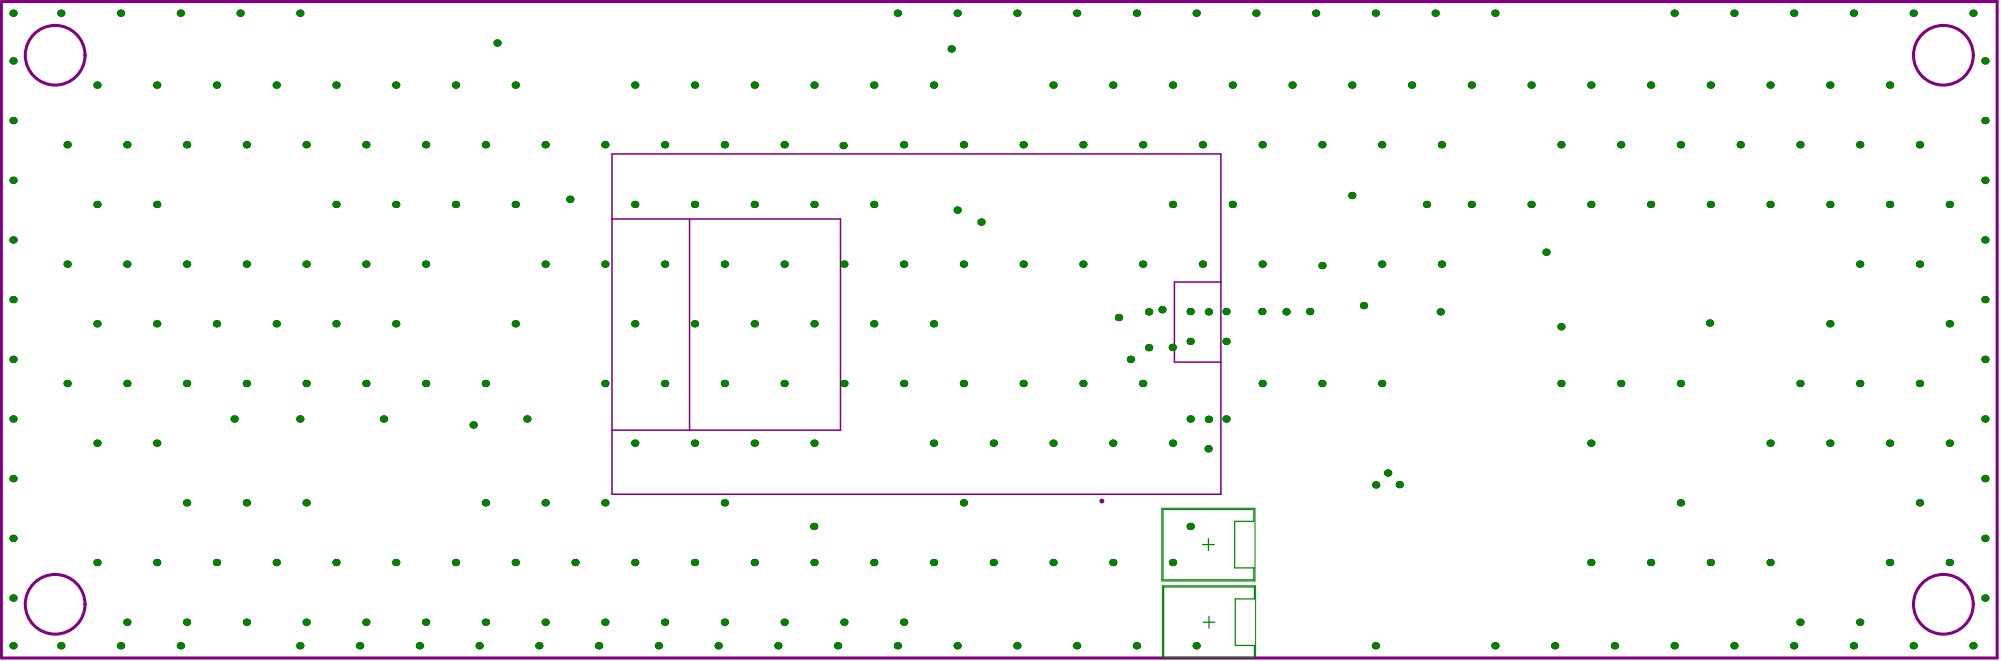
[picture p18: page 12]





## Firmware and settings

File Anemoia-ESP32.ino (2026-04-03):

#include <Arduino.h>
#include <SD.h>
#include <SPI.h>
#include <string>
#include <TFT_eSPI.h>
#include <WiFi.h>
#include <vector>

#include "src/core/bus.h"
#include "src/controller.h"
#include "src/debug.h"
#include "src/ui.h"
#include "config.h"
#include "hwconfig.h"
#include "driver/i2s.h"
#include "esp_wifi.h"
#include "esp_bt.h"
#include "esp_bt_main.h"

#ifndef OPTIMIZATION_FLAGS
#error The optimization flags were not applied! Please refer to *Step 4* of the README how to build and upload section.
#endif

HWConfig hw_config;
TFT_eSPI screen = TFT_eSPI();
SPIClass SD_SPI(SD_SPI_PORT);
UI ui(&screen);
Cartridge* cart;
void setup() 
{
    // Turn off Wifi and Bluetooth to reduce CPU overhead
    #ifdef DEBUG
        Serial.begin(115200);
        log_pin_config();
    #endif
    
    WiFi.mode(WIFI_OFF);
    esp_wifi_stop();
    esp_wifi_deinit();
    btStop();
    esp_bt_controller_disable();
    esp_bt_mem_release(ESP_BT_MODE_BTDM);
    esp_bt_controller_mem_release(ESP_BT_MODE_BTDM);

    hw_config = loadConfig();

    if (hw_config.backlight)
    {
        pinMode(TFT_BACKLIGHT_PIN, OUTPUT);
        ledcAttach(TFT_BACKLIGHT_PIN, BL_FREQ, BL_RESOLUTION);
        ledcWrite(TFT_BACKLIGHT_PIN, 255);
    }

    setupI2SDAC();

    // Initialize TFT screen
    screen.begin();
    screen.setRotation(hw_config.rotation);
    #ifndef DISABLE_DMA
        screen.initDMA();
    #endif
    screen.fillScreen(BG_COLOR);
    screen.startWrite();

    // Initialize microsd card
    if(!initSD()) while (true);
    ui.initializeSettings();

    // Setup buttons
    initController();
}

void loop() 
{
    cart = ui.selectGame();
    emulate();
}

#ifdef DEBUG
    unsigned long last_frame_time = 0;
    unsigned long current_frame_time = 0;
    unsigned long total_frame_time = 0;
    unsigned long frame_count = 0;
#endif
IRAM_ATTR void emulate()
{
    Bus nes;
    nes.insertCartridge(cart);
    nes.connectScreen(&screen);
    nes.reset();
    ui.loadEmulatorSettings(&nes);

    TaskHandle_t apu_task_handle;
    xTaskCreatePinnedToCore(
    apuTask,
    "APU Task",
    1024,
    &nes.cpu.apu,
    1,
    &apu_task_handle,
    0
    );

    TaskHandle_t polling_task_handle;
    xTaskCreatePinnedToCore(
    pollingTask,
    "Polling Task",
    768,
    &nes,
    1,
    &polling_task_handle,
    0
    );
    screen.setAddrWindow(32, 0, 256, 240);

    #ifdef DEBUG
        last_frame_time = esp_timer_get_time();
    #endif

    // Target frame time: 16639µs (60.098 FPS)
    #define FRAME_TIME 16639
    uint64_t next_frame = esp_timer_get_time();
    // Emulation Loop
    while (true) 
    {
        // Start + Select opens the pause menu
        if ((nes.controller & CONTROLLER::Start) && (nes.controller & CONTROLLER::Select)) 
        {
            if (!ui.paused)
            {
                vTaskSuspend(apu_task_handle);
                ui.pauseMenu(&nes);
                vTaskResume(apu_task_handle);
                next_frame = esp_timer_get_time() + FRAME_TIME;
                nes.controller = 0;
                screen.setAddrWindow(32, 0, 256, 240);
            }
        }

        // Generate one frame
        nes.clock();

        #ifdef DEBUG
            current_frame_time = esp_timer_get_time();
            total_frame_time += (current_frame_time - last_frame_time);
            frame_count++;

            if ((frame_count & 63) == 0)
            {
                float avg_fps = (1000000.0 * frame_count) / total_frame_time;
                LOGF("FPS: %.2f\n", avg_fps);
                total_frame_time = 0;
                frame_count = 0;
            }

            last_frame_time = current_frame_time;
        #endif

        // Frame limiting
        uint64_t now = esp_timer_get_time();
        #ifndef DEBUG
            if (now < next_frame) ets_delay_us(next_frame - now);
        #endif
        next_frame += FRAME_TIME;
    }
    #undef FRAME_TIME
}

bool initSD() 
{
    LOG("Initializing SD...");
    SD_SPI.begin(SD_SCLK_PIN, SD_MISO_PIN, SD_MOSI_PIN, SD_CS_PIN);
    if (!SD.begin(SD_CS_PIN, SD_SPI, hw_config.sd_freq * 1000000)) 
    {
        LOG("SD Card Mount Failed");

        screen.setTextSize(2);
        const char* txt1 = "SD Init failed!";
        const char* txt2 = "Insert SD card or";
        const char* txt3 = "lower SD frequency";
        const char* txt4 = "in config.h";
        int w1 = screen.textWidth(txt1, 2);
        int w2 = screen.textWidth(txt2, 2);
        int w3 = screen.textWidth(txt3, 2);
        int w4 = screen.textWidth(txt4, 2);
        
        int x1 = (320 - w1) / 2;
        int x2 = (320 - w2) / 2;
        int x3 = (320 - w3) / 2;
        int x4 = (320 - w4) / 2;

        screen.setTextColor(TFT_BLACK);
        screen.drawString(txt1, x1, 56, 2);
        screen.drawString(txt2, x2, 88, 2);
        screen.drawString(txt3, x3, 120, 2);
        screen.drawString(txt4, x4, 152, 2);
        return false;
    }

    return true;
}

void setupI2SDAC()
{
#if defined(CONFIG_IDF_TARGET_ESP32)
    i2s_config_t i2s_config = {
        .mode = (i2s_mode_t)(I2S_MODE_MASTER | I2S_MODE_TX | I2S_MODE_DAC_BUILT_IN),
        .sample_rate = SAMPLE_RATE,
        .bits_per_sample = I2S_BITS_PER_SAMPLE_16BIT,
        .channel_format = I2S_CHANNEL_FMT_ONLY_RIGHT,
        .communication_format = I2S_COMM_FORMAT_I2S_MSB,
        .intr_alloc_flags = 0,
        .dma_buf_count = 2,
        .dma_buf_len = 128,
        .use_apll = false,
        .tx_desc_auto_clear = true,
        .fixed_mclk = 0
    };

    if (hw_config.dac_pin == 1) i2s_config.channel_format = I2S_CHANNEL_FMT_ONLY_LEFT;
    i2s_driver_install(I2S_NUM_0, &i2s_config, 0, NULL);
    
    if (hw_config.dac_pin == 0)
        i2s_set_dac_mode(I2S_DAC_CHANNEL_RIGHT_EN);
    else if (hw_config.dac_pin == 1)
        i2s_set_dac_mode(I2S_DAC_CHANNEL_LEFT_EN);
#elif defined(CONFIG_IDF_TARGET_ESP32S3)
    i2s_config_t i2s_config = {
        .mode = (i2s_mode_t)(I2S_MODE_MASTER | I2S_MODE_TX),
        .sample_rate = SAMPLE_RATE,
        .bits_per_sample = I2S_BITS_PER_SAMPLE_16BIT,
        .channel_format = I2S_CHANNEL_FMT_RIGHT_LEFT,
        .communication_format = I2S_COMM_FORMAT_I2S_MSB,
        .intr_alloc_flags = 0,
        .dma_buf_count = 2,
        .dma_buf_len = 128,
        .use_apll = false,
        .tx_desc_auto_clear = true
    };

    esp_err_t err = i2s_driver_install(I2S_NUM_0, &i2s_config, 0, NULL);
    if (err != ESP_OK) {
        LOGF("I2S install failed: %d\n", err);
        return;
    }

    i2s_pin_config_t pin_config = {
        .bck_io_num = I2S_BCLK_PIN,
        .ws_io_num = I2S_LRC_PIN,
        .data_out_num = I2S_DOUT_PIN,
        .data_in_num = I2S_PIN_NO_CHANGE
    };
    err = i2s_set_pin(I2S_NUM_0, &pin_config);
    if (err != ESP_OK) {
        LOGF("I2S pin config failed: %d\n", err);
        return;
    }
    LOGF("I2S initialized: BCLK=%d, LRC=%d, DOUT=%d\n", I2S_BCLK_PIN, I2S_LRC_PIN, I2S_DOUT_PIN);
#endif
}

void apuTask(void* param) 
{
    Apu2A03* apu = (Apu2A03*)param;

    while (true)
    {
        apu->clock();
    }
}

void pollingTask(void* param)
{
    Bus* nes = (Bus*)param;
    const TickType_t frameTicks = pdMS_TO_TICKS(1000 / 60);
    TickType_t lastWakeTime = xTaskGetTickCount();

    while (true)
    {
        // Read button input
        nes->controller = controllerRead();

        vTaskDelayUntil(&lastWakeTime, frameTicks);
    }
    
}

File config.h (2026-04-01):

#ifndef CONFIG_H
#define CONFIG_H

// Controller Configuration
// 0 = CONTROLLER_GPIO, 1 = CONTROLLER_NES, 
// 2 = CONTROLLER_SNES, 3 = CONTROLLER_PSX
#define CONTROLLER_TYPE 0

// Screen Configuration
// #define TFT_BACKLIGHT_ENABLE // Uncomment this line if using a screen with backlight pin
#define TFT_BACKLIGHT_PIN 21
#define SCREEN_ROTATION 1 // Screen orientation: 1 or 3 (1 = landscape, 3 = landscape flipped)
#define SCREEN_SWAP_BYTES // Uncomment if colors appear wrong
// #define DISABLE_DMA // Uncomment this line if using parallel communication instead of SPI communication

// MicroSD card module Pins
#define SD_FREQ 80000000 // SD card SPI frequency (try lower if you have issues with SD card initialization, e.g. 4000000)
#define SD_MOSI_PIN 13
#define SD_MISO_PIN 12
#define SD_SCLK_PIN 14
#define SD_CS_PIN -1
#define SD_SPI_PORT HSPI 
// Use VSPI or HSPI depending on your wiring.
// SD_SPI_PORT should be the opposite SPI port from the one used by the display (e.g. if using HSPI for display, use VSPI for SD card, and vice versa).
// VSPI: MOSI=23, MISO=19, SCLK=18, CS=5 
// HSPI: MOSI=13, MISO=12, SCLK=14, CS=15

// Button pins
#define A_BUTTON 19
#define B_BUTTON 26
#define LEFT_BUTTON 32
#define RIGHT_BUTTON 33
#define UP_BUTTON 15
#define DOWN_BUTTON 4
#define START_BUTTON 27
#define SELECT_BUTTON 16

// NES controller pins
#define CONTROLLER_NES_CLK 32
#define CONTROLLER_NES_LATCH 33
#define CONTROLLER_NES_DATA 35

// SNES controller pins
#define CONTROLLER_SNES_CLK 32
#define CONTROLLER_SNES_LATCH 33
#define CONTROLLER_SNES_DATA 35

// PS1/PS2 controller pins
#define CONTROLLER_PSX_DATA 32
#define CONTROLLER_PSX_COMMAND 33
#define CONTROLLER_PSX_ATTENTION 26
#define CONTROLLER_PSX_CLK 27

#define DAC_PIN 0 // 0 = GPIO25, 1 = GPIO26

#define FRAMESKIP
// #define DEBUG // Uncomment this line if you want debug prints from serial


// If using an ESP32-S3
// External DAC pin configuration
#define I2S_BCLK_PIN   38   // Bit clock (BCLK)
#define I2S_LRC_PIN    39   // Word select / Left-Right clock (LRC / WS)
#define I2S_DOUT_PIN   40   // Serial data output (DIN)

#endif

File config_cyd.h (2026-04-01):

#ifndef CONFIG_CYD_H
#define CONFIG_CYD_H

// Controller Configuration
// Only NES controller supported for CYD
#define CONTROLLER_TYPE 1 // 1 = CONTROLLER_NES

// Screen Configuration
#define TFT_BACKLIGHT_ENABLE
#define TFT_BACKLIGHT_PIN 21
#define SCREEN_ROTATION 1 // Screen orientation: 1 or 3 (1 = landscape, 3 = landscape flipped)
#define SCREEN_SWAP_BYTES

// MicroSD card module Pins
#define SD_FREQ 80000000 // SD card SPI frequency (try lower if you have issues with SD card initialization, e.g. 4000000)
#define SD_MOSI_PIN 23
#define SD_MISO_PIN 19
#define SD_SCLK_PIN 18
#define SD_CS_PIN 5
#define SD_SPI_PORT VSPI 

// NES controller pins (CYD easily accessible GPIO pins)
#define CONTROLLER_NES_CLK 22
#define CONTROLLER_NES_LATCH 27
#define CONTROLLER_NES_DATA 35

// Unused button pins (set to -1 for CYD)
#define A_BUTTON -1
#define B_BUTTON -1
#define LEFT_BUTTON -1
#define RIGHT_BUTTON -1
#define UP_BUTTON -1
#define DOWN_BUTTON -1
#define START_BUTTON -1
#define SELECT_BUTTON -1

// Unused SNES controller pins (set to -1 for CYD)
#define CONTROLLER_SNES_CLK -1
#define CONTROLLER_SNES_LATCH -1
#define CONTROLLER_SNES_DATA -1

// Unused PS1/PS2 controller pins (set to -1 for CYD)
#define CONTROLLER_PSX_DATA -1
#define CONTROLLER_PSX_COMMAND -1
#define CONTROLLER_PSX_ATTENTION -1
#define CONTROLLER_PSX_CLK -1

#define DAC_PIN 1 // 0 = GPIO25, 1 = GPIO26 (CYD uses GPIO26)

#define FRAMESKIP
// #define DEBUG // Uncomment this line if you want debug prints from serial

#endif

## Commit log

2026-03-05 fix: use the correct ledc functions
    [Anemoia-ESP32.ino]
2026-03-07 chore(config): update pin configurations
2026-03-15 revert: "perf(render): update screen rendering function to pushPixels for improved performance"
    [Anemoia-ESP32.ino]
2026-03-15 chore: remove frame limiting for debug builds
2026-03-19 feat: add schematic and PCB files
    [Anemoia-ESP32-SMD_Bottom_Tenting.gbr, Anemoia-ESP32-SMD_Copper_Signal_Bot.gbr, Anemoia-ESP32-SMD_Copper_Signal_Top.gbr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]
2026-03-23 docs: add default pin schematic in README.md
2026-03-28 fix: update PSX controller data pin to GPIO17 as the data pin needs to be pulled up
    [config.h]
2026-04-01 fix: define unused button and controller pins for CYD
    [config_cyd.h]
2026-04-03 chore: add pin logging
